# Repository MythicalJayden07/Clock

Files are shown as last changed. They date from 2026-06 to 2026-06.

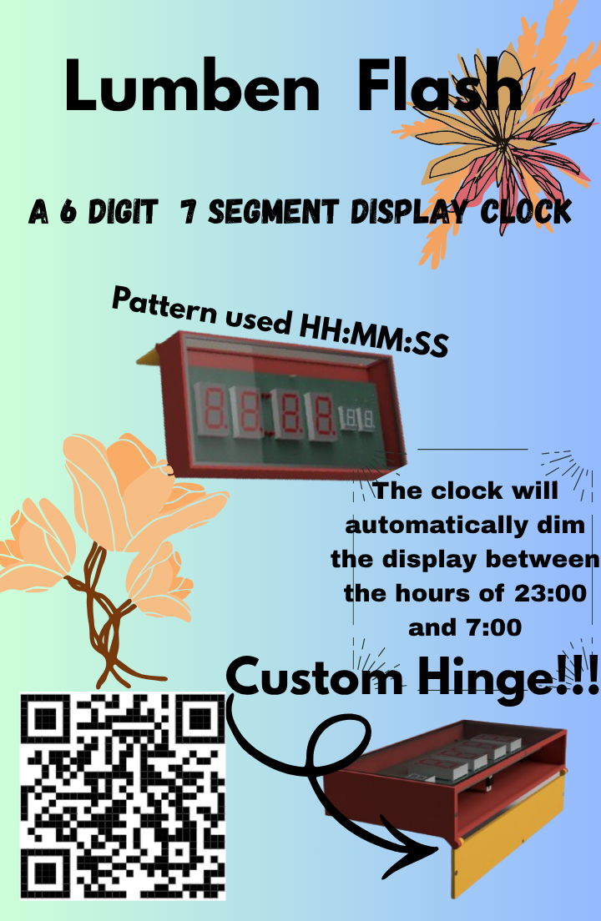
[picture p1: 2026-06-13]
Renders/fallout_zine_templateBLANK.pdf.png

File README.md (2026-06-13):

# 6-Digit 7-Segment Display Clock
This is a custom digital clock featuring a 6-digit 7-segment display packed into a clean, rectangular desktop case. I designed this to blend custom 3D-printed mechanics with a sleek, premium look by keeping the messy electronics hidden and using a real glass front panel.
## The Inspiration
I’ve always loved the raw, industrial look of 7-segment displays, but most DIY clocks you see online either look like a total rat's nest of bare wires or they’re stuck inside chunky 3D-printed plastic boxes that just feel a bit cheap.
I wanted to make something that actually looks like a premium desktop piece you'd buy at a store, while keeping that precise, retro-tech HH: MM :SS readout. The goal was to have a pristine glass front with zero visible screws or clunky printed bezels, but still have quick, toolless access to the PCB whenever I want to mess with the hardware.
## PCB Schematic
The brain of the clock. The schematic handles the multiplexing for the 6-digit display, power management, and the ATmega328P microcontroller layout to ensure clean signal lines without ghosting on the digits. 

## PCB Layout
A custom, compact board designed to slide perfectly into the case alignment channels. Component placement was adjusted so it sits perfectly behind the front glass face. 



## CAD Enclosure Design
The rectangular housing featuring the integrated top hinge and embedded slots for the neodymium magnets. This makes the door snap shut tight!!





## Bill of Materials (BOM)
[ClockBOM.csv](https://github.com/user-attachments/files/28500980/ClockBOM.csv)

| Reference | Qty | Value | Footprint / Details | Part Link |
| :--- | :---: | :--- | :--- | :--- |
| **U1** | 1 | ATmega328P-P | Package_DIP:DIP-28_W7.62mm Microcontroller | [Buy Link](https://www.mouser.in/ProductDetail/Microchip-Technology/ATMEGA328P-PU?qs=K8BHR703ZXguOQv3sKbWcg%3D%3D) |
| **U2 - U7** | 6 | TPIC6B595 | Package_DIP:DIP-20_W7.62mm Power Shift Register | [Buy Link](https://www.mouser.in/ProductDetail/Texas-Instruments/TPIC6B595N?qs=JHHQeKcAU3Cy7hDGJZD9fw%3D%3D) |
| **U8** | 1 | L7805 | Package_TO_SOT_THT:TO-220-3_Vertical Regulator | [Buy Link](https://www.mouser.in/ProductDetail/STMicroelectronics/L7805CV?qs=9NrABl3fj%2FqplZAHiYUxWg%3D%3D) |
| **DS1 - DS4** | 4 | SA18-11EWA | 1.8" Kingbright Red 7-Segment Display | [Buy Link](https://www.mouser.in/ProductDetail/Kingbright/SA18-11EWA?qs=JpELLRhtMc01ud%252BhiiNcbQ%3D%3D) |
| **DS5, DS6** | 2 | SA08-11GWA | 0.8" Kingbright Green 7-Segment Display | [Buy Link](https://www.mouser.in/ProductDetail/Kingbright/SA08-11GWA?qs=E09Sz5t5voVFPaAyTwzbvg%3D%3D) |
| **D1** | 1 | 1N5401 | Diode_THT:D_DO-201AD_Horizontal Rectifier | [Buy Link](https://www.mouser.in/ProductDetail/Diotec-Semiconductor/1N5401?qs=OlC7AqGiEDkgsZqkfh5%2F5g%3D%3D) |
| **Q1** | 1 | 2N3904 | Package_TO_SOT_THT:TO-92_Inline NPN Transistor | [Buy Link](https://www.mouser.in/ProductDetail/onsemi/2N3904BU?qs=or4AE2qAS%252Bd0Jdpn%2F8ktKg%3D%3D) |
| **F1** | 1 | 2A | Fuse:Fuse_Bourns_MF-RG300 Resettable PTC | [Buy Link](https://www.mouser.in/ProductDetail/Bourns/MF-RG300-0?qs=Zco4Fs67ctclSu06fHwNtw%3D%3D) |
| **Y1** | 1 | 16Mhz | Crystal:Crystal_HC49-U_Vertical Oscillator | [Buy Link](https://robu.in/product/hc49-s-16mhz-crystal-oscillator-pack-of-5/) |
| **C1** | 1 | 470uf | Capacitor_THT:CP_Radial_D8.0mm 25V Electrolytic | [Buy Link](https://robu.in/product/470uf-25v-electrolytic-capacitor-pack-of-3/) |
| **C3** | 1 | 100uf | Capacitor_THT:CP_Radial_D8.0mm 25V Electrolytic | [Buy Link](https://robu.in/?s=100uf+25v+radial+electrolyte+capacitor&post_type=product) |
| **C2, C4-C12, C15** | 11 | 100n | Capacitor_THT:C_Disc 0.1uF Ceramic Disc | [Buy Link](https://robu.in/?s=104+0.1uf+ceramic+disc+capacitor&post_type=product) |
| **C13, C14** | 2 | 22pf | Capacitor_THT:C_Disc 22pF Ceramic Disc | [Buy Link](https://robu.in/?s=22pf+ceramic+disc+capacitor&post_type=product) |
| **D2 - D5** | 4 | LED | LED_THT:LED_D5.0mm Red Status Indicator | [Buy Link](https://robu.in/?s=5mm+red+led+pack&post_type=product) |
| **R1-R7, R9-R15, R17-R23, R26-R32** | 28 | 390R | Resistor_THT:R_Axial 1/4W Carbon Film | (https://robu.in/?s=390+ohm+quarter+watt+resistor&post_type=product) |
| **R8, R16, R24, R33, R35-R50** | 20 | 620R | Resistor_THT:R_Axial 1/4W Carbon Film | (https://robu.in/?s=620+ohm+quarter+watt+resistor&post_type=product) |
| **R51, R55** | 2 | 1k | Resistor_THT:R_Axial 1/4W Carbon Film | (https://robu.in/?s=1k+ohm+quarter+watt+resistor&post_type=product) |
| **R52** | 1 | 270R | Resistor_THT:R_Axial 1/4W Carbon Film | (https://robu.in/?s=270+ohm+quarter+watt+resistor&post_type=product) |
| **R53, R54** | 2 | 10k | Resistor_THT:R_Axial 1/4W Carbon Film | (https://robu.in/?s=10k+ohm+quarter+watt+resistor&post_type=product) |
| **J1, J4** | 2 | Male Pins | 2.54mm Breakaway Vertical Headers | [Buy Link](https://www.digikey.in/en/products/detail/amphenol-cs-fci/68000-402HLF/1493940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 and https://www.digikey.in/en/products/detail/amphenol-cs-fci/68000-406HLF/1878471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 ) |
| **J2, J3** | 2 | Sockets | 2.54mm Vertical Female Pin Sockets | [Buy Link](https://www.digikey.in/en/products/detail/3m/929974-01-04-RK/1094257 and https://www.digikey.in/en/products/detail/3m/929974-01-06-RK/1094259) |
| **Case Hardware** | 6 | Magnets | N52 Neodymium Disc Magnets (3mm x 2mm) | [Buy Link](https://www.amazon.in/dp/B0BN8PHN9B) |
| **Case Hardware** | 1 | Glass Sheet | Custom cut clear front panel window (2mm) |  |

```

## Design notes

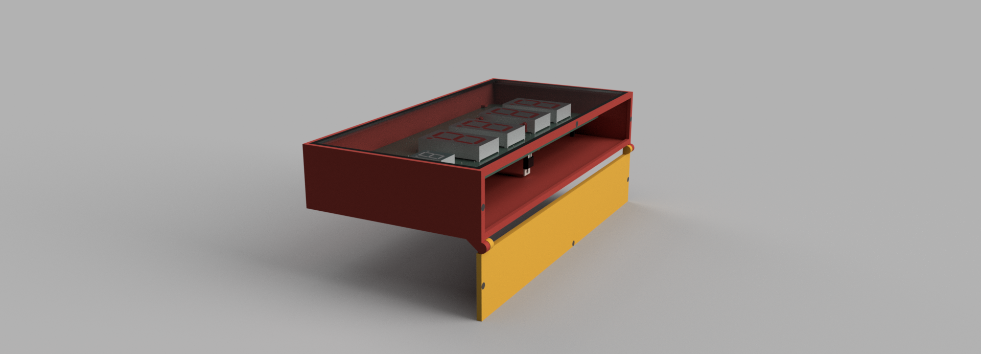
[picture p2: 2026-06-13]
Renders/clockrender2.png

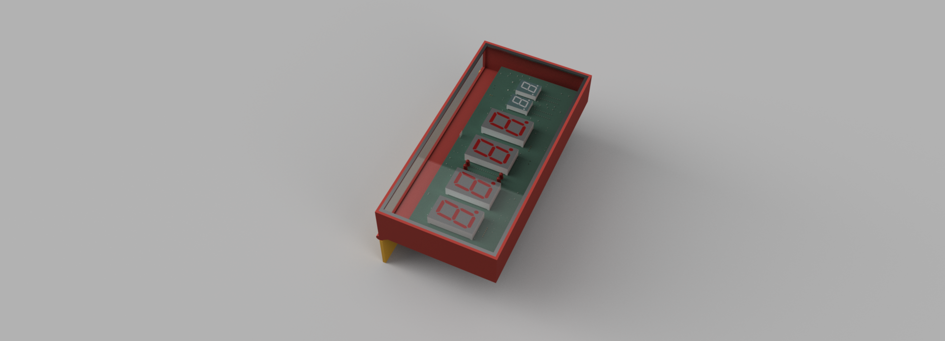
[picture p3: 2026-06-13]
Renders/clockrender1.png

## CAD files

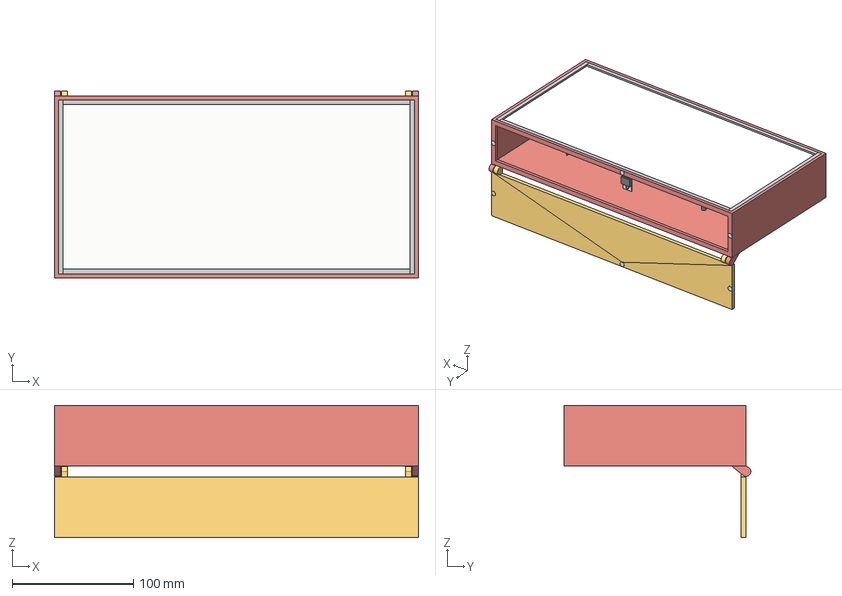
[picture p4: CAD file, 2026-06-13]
CAD/clockassembly.step
300.0 x 154.0 x 109.0 mm
TO-92_Inline
PinHeader_1x02_P2.54mm_Vertical
Crystal_HC49-U_Vertical
DIP-28_W7.62mm
TO-220-3_Vertical
D_DO-201AD_P15.24mm_Horizontal
PinSocket_1x04_P2.54mm_Vertical
PinSocket_1x06_P2.54mm_Vertical
PinHeader_1x06_P2.54mm_Vertical
Clock_PCB

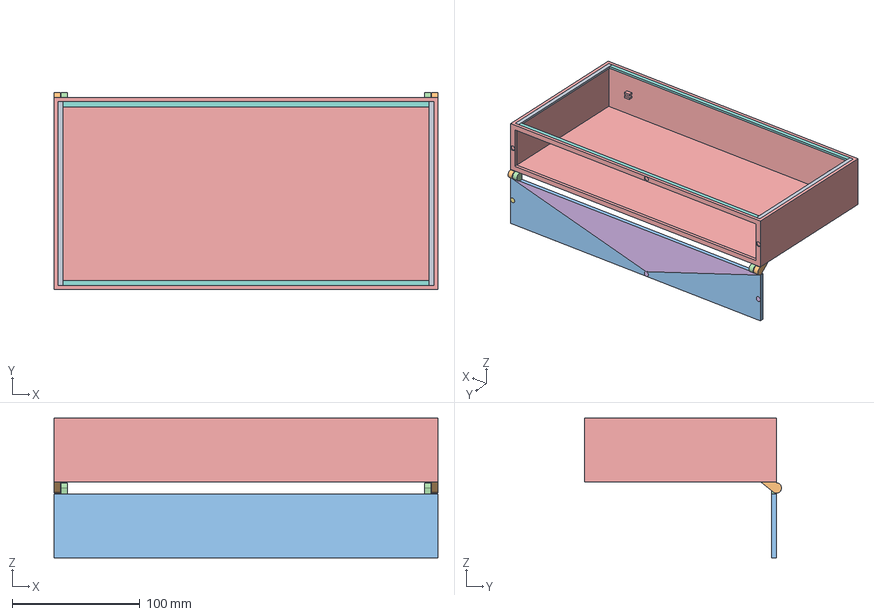
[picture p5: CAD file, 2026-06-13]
CAD/Clock case.step
300.0 x 154.0 x 109.0 mm

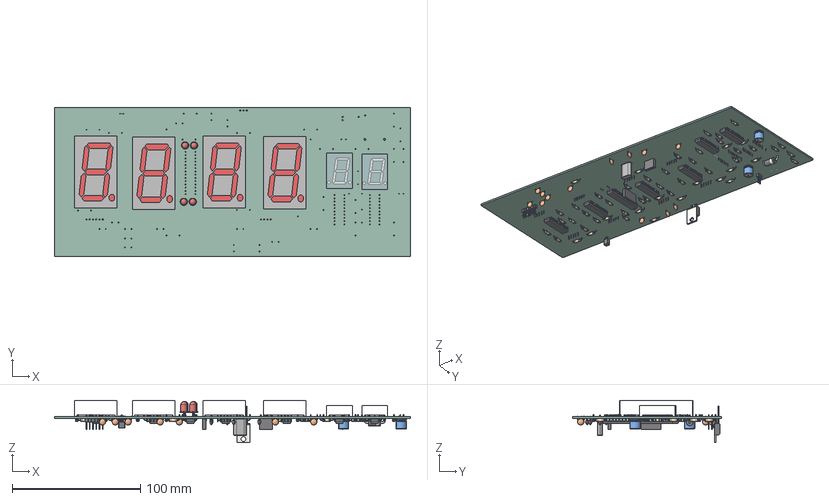
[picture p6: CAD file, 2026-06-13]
CAD/clock_PCB.step
278.0 x 116.1 x 33.0 mm
LED_D5.0mm x 4
SA18-11EWA x 4
SA08-11GWA x 2
TO-92_Inline
R_Axial_DIN0207_L6.3mm_D2.5mm_P10.16mm_Horizontal x 53
DIP-20_W7.62mm x 6
C_Disc_D5.0mm_W2.5mm_P5.00mm x 13
PinHeader_1x02_P2.54mm_Vertical
CP_Radial_D8.0mm_P3.50mm x 2
Crystal_HC49-U_Vertical
DIP-28_W7.62mm
TO-220-3_Vertical
D_DO-201AD_P15.24mm_Horizontal
PinSocket_1x04_P2.54mm_Vertical
PinSocket_1x06_P2.54mm_Vertical
PinHeader_1x06_P2.54mm_Vertical
Clock_PCB

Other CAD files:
CAD/Clock case.f3d
CAD/clockAssembly.f3z

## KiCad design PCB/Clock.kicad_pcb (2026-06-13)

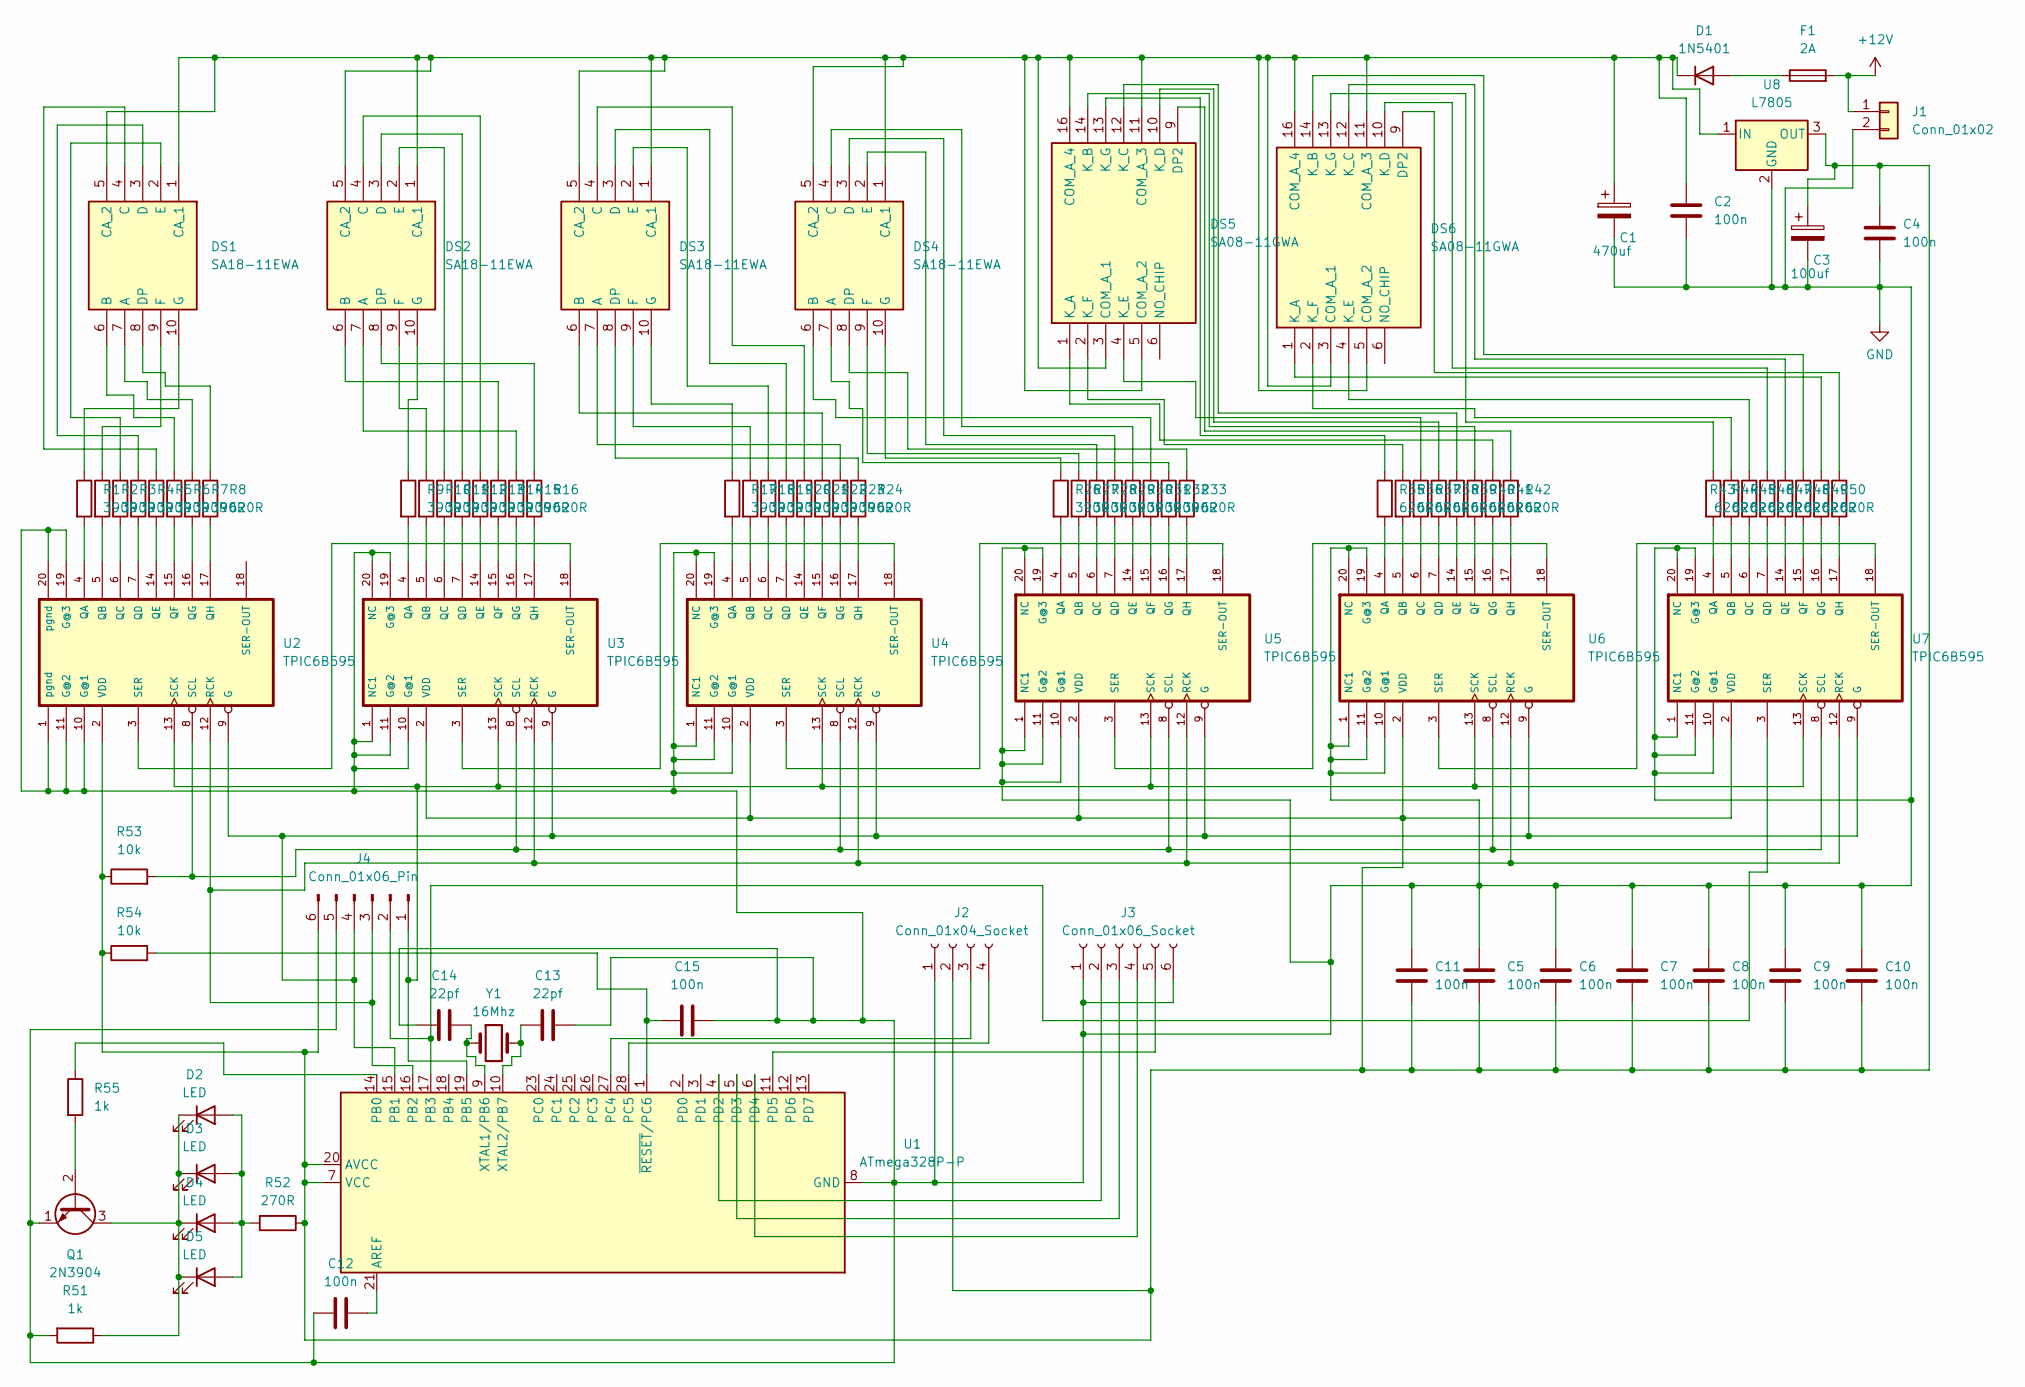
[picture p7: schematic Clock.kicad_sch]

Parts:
C1: 470uf; CP_Radial_D8.0mm_P3.50mm
C2, C4, C5, C6, C7, C8, C9, C10, C11, C12, C15: 100n; C_Disc_D5.0mm_W2.5mm_P5.00mm
C3: 100uf; CP_Radial_D8.0mm_P3.50mm
C13, C14: 22pf; C_Disc_D5.0mm_W2.5mm_P5.00mm
D1: 1N5401; D_DO-201AD_P15.24mm_Horizontal
D2, D3, D4, D5: LED; LED_D5.0mm
DS1, DS2, DS3, DS4: SA18-11EWA; My_Big_SA18_Display; Manufacturer_Part_Number SA18-11EWA; Mouser Part Number 604-SA18-11EWA
DS5, DS6: SA08-11GWA; My_Custom_SA08_Display; Manufacturer_Part_Number SA08-11GWA; Mouser Part Number 604-SA08-11GWA
F1: 2A; Fuse_Bourns_MF-RG300
J1: Conn_01x02; PinHeader_1x02_P2.54mm_Vertical
J2: Conn_01x04_Socket; PinSocket_1x04_P2.54mm_Vertical
J3: Conn_01x06_Socket; PinSocket_1x06_P2.54mm_Vertical
J4: Conn_01x06_Pin; PinHeader_1x06_P2.54mm_Vertical
Q1: 2N3904; TO-92_Inline
R1, R2, R3, R4, R5, R6, R7, R9, R10, R11, R12, R13, R14, R15, R17, R18, R19, R20, R21, R22, R23, R26, R27, R28, R29, R30, R31, R32: 390R; R_Axial_DIN0207_L6.3mm_D2.5mm_P10.16mm_Horizontal
R8, R16, R24, R33, R35, R36, R37, R38, R39, R40, R41, R42, R43, R44, R45, R46, R47, R48, R49, R50: 620R; R_Axial_DIN0207_L6.3mm_D2.5mm_P10.16mm_Horizontal
R51, R55: 1k; R_Axial_DIN0207_L6.3mm_D2.5mm_P10.16mm_Horizontal
R52: 270R; R_Axial_DIN0207_L6.3mm_D2.5mm_P10.16mm_Horizontal
R53, R54: 10k; R_Axial_DIN0207_L6.3mm_D2.5mm_P10.16mm_Horizontal
U1: ATmega328P-P; DIP-28_W7.62mm
U2, U3, U4, U5, U6, U7: TPIC6B595; DIP-20_W7.62mm
U8: L7805; TO-220-3_Vertical
Y1: 16Mhz; Crystal_HC49-U_Vertical

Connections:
+12V: F1.2, J1.1
GND: C1.2, C2.2, C3.2, C4.2, C5.1, C6.1, C7.1, C8.1, C9.1, C10.1, C11.1, C12.1, C13.2, C14.1, C15.2, J1.2, J2.1, J3.1, J3.6, J4.5, Q1.1 (E), R51.2, U1.8 (GND), U1.22 (GND), U2.1 (pgnd), U2.10 (G@1), U2.11 (G@2), U2.19 (G@3), U2.20 (pgnd), U3.1 (NC1), U3.10 (G@1), U3.11 (G@2), U3.19 (G@3), U3.20 (NC), U4.1 (NC1), U4.10 (G@1), U4.11 (G@2), U4.19 (G@3), U4.20 (NC), U5.1 (NC1), U5.10 (G@1), U5.11 (G@2), U5.19 (G@3), U5.20 (NC), U6.1 (NC1), U6.10 (G@1), U6.11 (G@2), U6.19 (G@3), U6.20 (NC), U7.1 (NC1), U7.10 (G@1), U7.11 (G@2), U7.19 (G@3), U7.20 (NC), U8.2 (GND)
unnamed: D1.2 (A), F1.1
unnamed: C1.1, C2.1, D1.1 (K), DS1.1 (CA_1), DS1.5 (CA_2), DS2.1 (CA_1), DS2.5 (CA_2), DS3.1 (CA_1), DS3.5 (CA_2), DS4.1 (CA_1), DS4.5 (CA_2), DS5.3 (COM_A_1), DS5.5 (COM_A_2), DS5.11 (COM_A_3), DS5.16 (COM_A_4), DS6.3 (COM_A_1), DS6.5 (COM_A_2), DS6.11 (COM_A_3), DS6.16 (COM_A_4), U8.1 (IN)
unnamed: D2.2 (A), D3.2 (A), D4.2 (A), D5.2 (A), R52.2
unnamed: D2.1 (K), D3.1 (K), D4.1 (K), D5.1 (K), Q1.3 (C), R51.1
unnamed: DS1.7 (A), R7.1
unnamed: DS1.6 (B), R6.1
unnamed: DS1.4 (C), R5.1
unnamed: DS1.3 (D), R4.1
unnamed: DS1.8 (DP), R8.1
unnamed: DS1.2 (E), R3.1
unnamed: DS1.9 (F), R2.1
unnamed: DS1.10 (G), R1.1
unnamed: DS2.7 (A), R15.1
unnamed: DS2.6 (B), R14.1
unnamed: DS2.4 (C), R13.1
unnamed: DS2.3 (D), R12.1
unnamed: DS2.8 (DP), R16.1
unnamed: DS2.2 (E), R11.1
unnamed: DS2.9 (F), R10.1
unnamed: DS2.10 (G), R9.1
unnamed: DS3.7 (A), R23.1
unnamed: DS3.6 (B), R22.1
unnamed: DS3.4 (C), R21.1
unnamed: DS3.3 (D), R20.1
unnamed: DS3.8 (DP), R24.1
unnamed: DS3.2 (E), R19.1
unnamed: DS3.9 (F), R18.1
unnamed: DS3.10 (G), R17.1
unnamed: DS4.7 (A), R32.1
unnamed: DS4.6 (B), R31.1
unnamed: DS4.4 (C), R30.1
unnamed: DS4.3 (D), R29.1
unnamed: DS4.8 (DP), R33.1
unnamed: DS4.2 (E), R28.1
unnamed: DS4.9 (F), R27.1
unnamed: DS4.10 (G), R26.1
unnamed: DS5.9 (DP2), R42.1
unnamed: DS5.1 (K_A), R41.1
unnamed: DS5.14 (K_B), R40.1
unnamed: DS5.12 (K_C), R39.1
unnamed: DS5.10 (K_D), R38.1
unnamed: DS5.4 (K_E), R37.1
unnamed: DS5.2 (K_F), R36.1
unnamed: DS5.13 (K_G), R35.1
unnamed: DS6.9 (DP2), R43.1
unnamed: DS6.1 (K_A), R50.1
unnamed: DS6.14 (K_B), R49.1
unnamed: DS6.12 (K_C), R48.1
unnamed: DS6.10 (K_D), R47.1
unnamed: DS6.4 (K_E), R46.1
unnamed: DS6.2 (K_F), R45.1
unnamed: DS6.13 (K_G), R44.1
unnamed: C3.1, C4.1, C5.2, C6.2, C7.2, C8.2, C9.2, C10.2, C11.2, J2.2, J4.6, R52.1, R53.1, R54.1, U1.7 (VCC), U1.20 (AVCC), U2.2 (VDD), U3.2 (VDD), U4.2 (VDD), U5.2 (VDD), U6.2 (VDD), U7.2 (VDD), U8.3 (OUT)
unnamed: J2.3, U1.27 (PC4)
unnamed: J2.4, U1.28 (PC5)
unnamed: J3.2, U1.4 (PD2)
unnamed: J3.3, U1.5 (PD3)
unnamed: J3.4, U1.6 (PD4)
unnamed: J3.5, U1.11 (PD5)
unnamed: J4.1, U1.19 (PB5), U2.13 (SCK), U3.13 (SCK), U4.13 (SCK), U5.13 (SCK), U6.13 (SCK), U7.13 (SCK)
unnamed: J4.2, U1.17 (PB3), U7.3 (SER)
unnamed: J4.3, U1.16 (PB2), U2.12 (RCK), U3.12 (RCK), U4.12 (RCK), U5.12 (RCK), U6.12 (RCK), U7.12 (RCK)
unnamed: J4.4, U1.15 (PB1), U2.9 (G), U3.9 (G), U4.9 (G), U5.9 (G), U6.9 (G), U7.9 (G)
unnamed: Q1.2 (B), R55.2
unnamed: C12.2, U1.21 (AREF)
unnamed: R55.1, U1.14 (PB0)
unnamed: C14.2, U1.9 (XTAL1/PB6), Y1.1
unnamed: C13.1, U1.10 (XTAL2/PB7), Y1.2
unnamed: C15.1, R54.2, U1.1 (~RESET/PC6)
unnamed: R1.2, U2.4 (QA)
unnamed: R2.2, U2.5 (QB)
unnamed: R3.2, U2.6 (QC)
unnamed: R4.2, U2.7 (QD)
unnamed: R5.2, U2.14 (QE)
unnamed: R6.2, U2.15 (QF)
unnamed: R7.2, U2.16 (QG)
unnamed: R8.2, U2.17 (QH)
unnamed: R53.2, U2.8 (SCL), U3.8 (SCL), U4.8 (SCL), U5.8 (SCL), U6.8 (SCL), U7.8 (SCL)
unnamed: U2.3 (SER), U3.18 (SER-OUT)
unnamed: R9.2, U3.4 (QA)
unnamed: R10.2, U3.5 (QB)
unnamed: R11.2, U3.6 (QC)
unnamed: R12.2, U3.7 (QD)
unnamed: R13.2, U3.14 (QE)
unnamed: R14.2, U3.15 (QF)
unnamed: R15.2, U3.16 (QG)
unnamed: R16.2, U3.17 (QH)
unnamed: U3.3 (SER), U4.18 (SER-OUT)
unnamed: R17.2, U4.4 (QA)
unnamed: R18.2, U4.5 (QB)
unnamed: R19.2, U4.6 (QC)
unnamed: R20.2, U4.7 (QD)
unnamed: R21.2, U4.14 (QE)
unnamed: R22.2, U4.15 (QF)
unnamed: R23.2, U4.16 (QG)
unnamed: R24.2, U4.17 (QH)
unnamed: U4.3 (SER), U5.18 (SER-OUT)
unnamed: R26.2, U5.4 (QA)
unnamed: R27.2, U5.5 (QB)
unnamed: R28.2, U5.6 (QC)
unnamed: R29.2, U5.7 (QD)
unnamed: R30.2, U5.14 (QE)
unnamed: R31.2, U5.15 (QF)
unnamed: R32.2, U5.16 (QG)
unnamed: R33.2, U5.17 (QH)
unnamed: U5.3 (SER), U6.18 (SER-OUT)
unnamed: R35.2, U6.4 (QA)
unnamed: R36.2, U6.5 (QB)
unnamed: R37.2, U6.6 (QC)
unnamed: R38.2, U6.7 (QD)
unnamed: R39.2, U6.14 (QE)
unnamed: R40.2, U6.15 (QF)
unnamed: R41.2, U6.16 (QG)
unnamed: R42.2, U6.17 (QH)
unnamed: U6.3 (SER), U7.18 (SER-OUT)
unnamed: R44.2, U7.4 (QA)
unnamed: R45.2, U7.5 (QB)
unnamed: R46.2, U7.6 (QC)
unnamed: R47.2, U7.7 (QD)
unnamed: R48.2, U7.14 (QE)
unnamed: R49.2, U7.15 (QF)
unnamed: R50.2, U7.16 (QG)
unnamed: R43.2, U7.17 (QH)

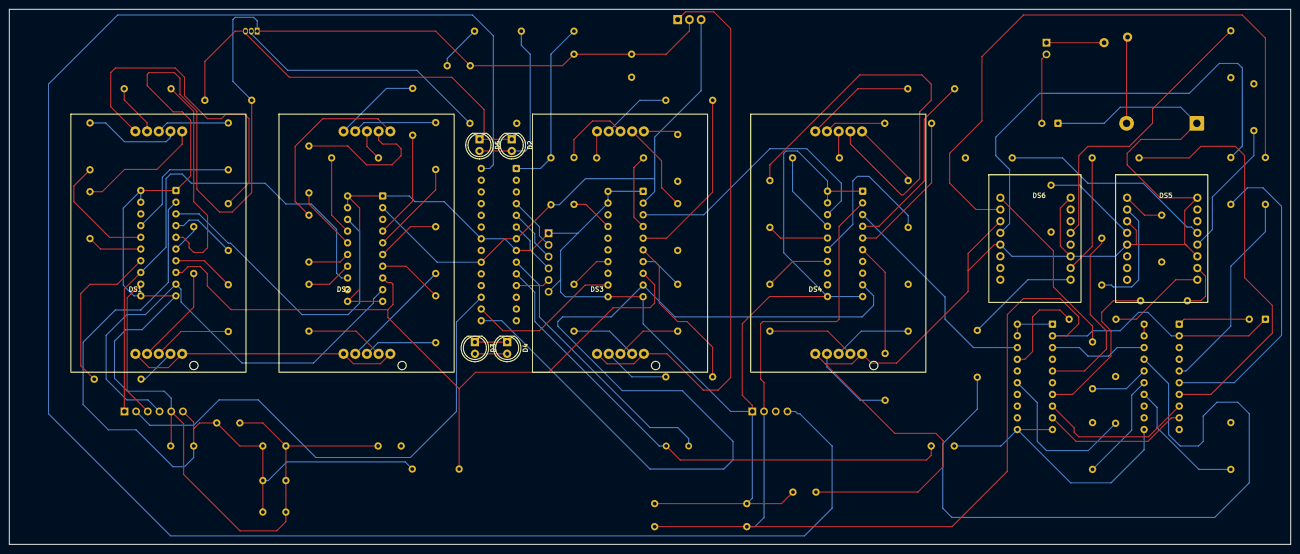
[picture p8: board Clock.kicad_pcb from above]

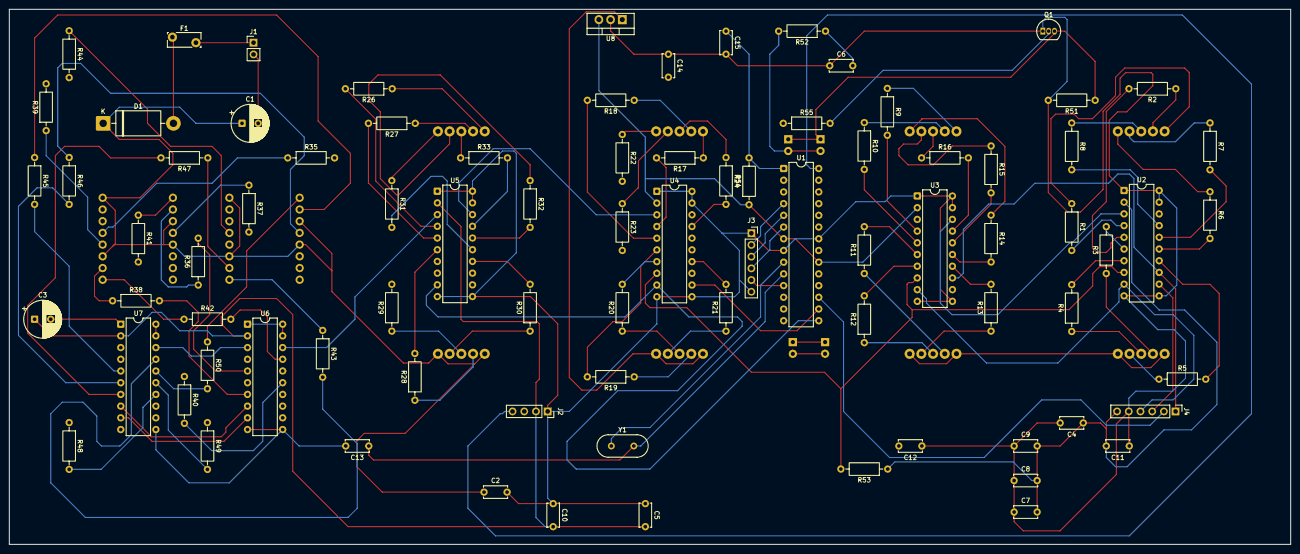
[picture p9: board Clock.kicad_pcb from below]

Board: 4 copper layers, 278.0 x 116.1 mm, 94 parts (84 on the bottom side), 125 nets.

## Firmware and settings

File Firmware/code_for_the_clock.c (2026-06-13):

// 6 Digit clock using TPIC6B595 shift registers
// Leftmost digit is digit 0
// Data will be fed in to the rightmost register first so digit 0 needs shifting out first. 
// The clock will have 3 buttons - hour set, min set and enter / exit set mode.
// To set the time press the set button and the clock will go to the set time function - this is detected in main loop.
// To exit time set function press set button again, this will also zero the seconds and write new values to the rtc.
// A 4th button could be used to display temperature - not sure about this yet.

// 7-segment digits 0-9
// {Q0, Q1, Q2, Q3, Q4, Q5, Q6, Q7} --> {g, f, e, d, c, b, a, DP} 

#include <SPI.h>
#include <SoftPWM.h>
#include <Wire.h>                        
#include <RTClib.h>
#include "Button.h"  // Button library by Alexander Brevig                      

const int reg_clock = 13; // SRCK
const int reg_latch = 10; // RCLK
const int reg_data = 11; // SER_IN
const int reg_OE = 9; // output enable; Active LOW. Can be used to control brightness with PWM.
const int colon_pin = 8; // used to dim the colon LED's when night mode enabled.

Button button1 = Button(2,BUTTON_PULLUP_INTERNAL);       // Setup button A (using button library)
Button button2 = Button(3,BUTTON_PULLUP_INTERNAL);       // Setup button B (using button library)
Button button3 = Button(4,BUTTON_PULLUP_INTERNAL);       // Setup button A (using button library)
Button button4 = Button(5,BUTTON_PULLUP_INTERNAL);       // Setup button B (using button library)

int brightness = 4; // set display brightness. Values 1-5. Set to level 4 as LED's I chose were eye searingly bright at level 5.
int brt = 0; // value for storing reversed PWM percentage
int set_mode = 0; // value for storing timeset mode true or false

#define DS3231_I2C_ADDR 0x68
#define DS3231_TEMPERATURE_ADDR 0x11

RTC_DS3231 rtc;

byte ssddigits[10] = // array without decimal points on
{
  B01111110,  // 0
  B00001100,  // 1
  B10110110,  // 2
  B10011110,  // 3
  B11001100,  // 4
  B11011010,  // 5
  B11111010,  // 6
  B01001110,  // 7
  B11111110,  // 8
  B11011110,  // 9
};

byte ssddigitsDP[10] = // array with decimal points on
{
  B01111111,  // 0
  B00001101,  // 1
  B10110111,  // 2
  B10011111,  // 3
  B11001101,  // 4
  B11011011,  // 5
  B11111011,  // 6
  B01001111,  // 7
  B11111111,  // 8
  B11011111,  // 9
};

byte tempC[2] = // C and degrees symbol
{
  B01110010,
  B11000110,
}; 

void setup() // runs once at powerup
{
  
  pinMode (reg_clock, OUTPUT);
  pinMode (reg_latch, OUTPUT);
  pinMode (reg_data, OUTPUT);
  pinMode (reg_OE,OUTPUT);
  pinMode (colon_pin, OUTPUT);
  digitalWrite(reg_OE,LOW); // enable output of shift register chain; an external pullup resistor on the OE pin prevents garbage being displayed at power on.
  digitalWrite(colon_pin, HIGH); // set colons to bright initially
  setBrt();
  SoftPWMBegin();
  SoftPWMSet(9, 0); // init software PWM on pin 9. This pulses the OE pin on and off to control brightness.
  SoftPWMSetPercent(9, brt);
  Wire.begin(); // start i2c 
  rtc.begin(); //start RTC Clock
  set_mode = 0; // set timeset mode to off
             
  //rtc.adjust(DateTime(F(__DATE__), F(__TIME__))); // comment out once clock is initialy set
    
}

void loop() // main program loop
{
   if (set_mode == 1)

   {
     setTime();
   }

   else
   {
     clockDisplay();
   }
   
   if (button1.uniquePress())
   {
    SPI.beginTransaction(SPISettings(8000000, LSBFIRST, SPI_MODE0)); // display "set" for 2 seconds
    digitalWrite(reg_latch,LOW);
    SPI.transfer(B11011010); // S
    SPI.transfer(B11110010); // E
    SPI.transfer(B11110000); // t
    SPI.transfer(B00000000); // blank digit 3
    SPI.transfer(B00000000); // blank seconds display 10s
    SPI.transfer(B00000000); // blank seconds display 1s 
    digitalWrite(reg_latch,HIGH);
    SPI.endTransaction();
    delay(2000);
    set_mode = 1; // enter timeset mode
   }

  setBrt();
  SoftPWMSetPercent(9, brt); 
}

/// functions ///

void clockDisplay() // gets the time from the rtc and sends data to the shift registers.
{

  DateTime now = rtc.now();

  int hours = now.hour();  
	int minutes = now.minute();
  int seconds = now.second();  

  int h1, h2, m1, m2, s1, s2; // split the numbers into seperate digits using mod math
	h2 = hours % 10;
	h1 = ((hours % 100) - h1) / 10;
	m2 = minutes % 10;
	m1 = ((minutes % 100) - m1) / 10;
  s2 = seconds % 10;
  s1 = ((seconds % 100) - s1) / 10;

  // get digit 0
  int dig0 = (h1); // 10h
  // get digit 1
  int dig1 = (h2); // 1h
  // get digit 2
  int dig2 = (m1); // 10m
  // get digit 3
  int dig3 = (m2); // 1m
  // get digit 4
  int dig4 = (s1); // 10s
  // get digit 5
  int dig5 = (s2); // 1s

  SPI.beginTransaction(SPISettings(8000000, LSBFIRST, SPI_MODE0)); // send data to shift registers
  digitalWrite(reg_latch,LOW);
  SPI.transfer(ssddigits[dig0]); 
  SPI.transfer(ssddigits[dig1]);
  SPI.transfer(ssddigits[dig2]);
  SPI.transfer(ssddigits[dig3]);
  SPI.transfer(ssddigits[dig4]);
  SPI.transfer(ssddigits[dig5]);
  digitalWrite(reg_latch,HIGH);
  SPI.endTransaction();

 if (now.hour() == 23 && now.minute() == 0 && now.second() == 0) // dim display at 23:00
    {
       brightness = 1;
       digitalWrite(colon_pin, LOW); // set colon to dim
    }

    if (now.hour() == 7 && now.minute() == 0 && now.second() == 0) // resume normal brightness at 7:00
    {
       brightness = 4;
       digitalWrite(colon_pin, HIGH); // set colon to bright.
    }

}

void setTime() // this will run if hour or minute set button is pressed

{
    
  DateTime now = rtc.now(); // this gets the current time from the RTC so it updates after button presses.
  int set_min = now.minute();
  int set_hour  = now.hour();
 
  int h1, h2, m1, m2; // split the numbers into seperate digits using mod math
	h2 = set_hour % 10;
	h1 = ((set_hour % 100) - h1) / 10;
	m2 = set_min % 10;
	m1 = ((set_min % 100) - m1) / 10;

  // get digit 0
  int dig0 = (h1); // 10h
  // get digit 1
  int dig1 = (h2); // 1h
  // get digit 2
  int dig2 = (m1); // 10m
  // get digit 3
  int dig3 = (m2); // 1m

  SPI.beginTransaction(SPISettings(8000000, LSBFIRST, SPI_MODE0)); // send data to shift registers
  digitalWrite(reg_latch,LOW);
  SPI.transfer(ssddigits[dig0]); 
  SPI.transfer(ssddigits[dig1]);
  SPI.transfer(ssddigits[dig2]);
  SPI.transfer(ssddigits[dig3]);
  SPI.transfer(B00000000); // blank seconds display 10s
  SPI.transfer(B00000001); // blank seconds display 1s & light last decimal point to indicate set mode
  digitalWrite(reg_latch,HIGH);
  SPI.endTransaction();
     
  // code here will increment values above if hour and minute buttons are pressed also sets button_pressed flag to true

  while (button2.uniquePress())
    {
      set_hour++;
      if (set_hour == 24)
      {
        set_hour = 0;
      }
      delay(10); // 10 millisecond delay to avoid spamming the RTC
      rtc.adjust(DateTime(2023, 10, 23, set_hour, set_min)); // write the time to the rtc, dont zero seconds
    }

  while (button3.uniquePress())
    {
      set_min++;

      if (set_min == 60)
      {
        set_min = 0;
      }
      delay(10); // 10 millisecond delay to avoid spamming the RTC
      rtc.adjust(DateTime(2023, 10, 23, set_hour, set_min)); // write the time to the rtc, don't zero seconds
    }  
   
   if (button1.uniquePress())
    {
      DateTime now = rtc.now(); // this gets the current time from the RTC so it updates after button presses.
      int set_min = now.minute();
      int set_hour  = now.hour();
      rtc.adjust(DateTime(2023, 10, 23, set_hour, set_min,0)); // zero seconds when set button is pressed again
      set_mode = 0; // this happens if timeset button is pressed after adjusting the time
      clockDisplay(); // exit function and return to clock display
    }

}

void setBrt() // this changes the brightness logarithmic reversed scale to a more linear one

{
  if (brightness == 1)
  brt = 90;

  else if (brightness == 2)
  brt = 75;

  else if (brightness == 3)
  brt = 50;

  else if (brightness == 4)
  brt = 30;

  else if (brightness == 5)
  brt = 0;
}

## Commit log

2026-06-02 Enhance README with project details and BOM
    Expanded the README to include detailed project information, inspiration, PCB schematic, layout, CAD design, and a comprehensive Bill of Materials (BOM).
2026-06-02 Enhance README with BOM links and supplier information
    Updated the README to include a link to the BOM CSV file and added supplier links for components in the Bill of Materials section.
2026-06-02 Add Bill of Materials section to README
    Added a detailed Bill of Materials (BOM) section with components, quantities, values, footprints, and purchase links.
2026-06-02 Enhance README with Bill of Materials details
    Added detailed Bill of Materials (BOM) section with references, quantities, and links for components.
2026-06-02 Fix formatting in Bill of Materials section
2026-06-02 Update magnet quantity in hardware list
    Updated the quantity of N52 Neodymium Disc Magnets from 4 to 6 in the hardware list.
2026-06-13 Refactor Bill of Materials section in README
    Removed duplicate Bill of Materials section and updated links for resistors.
